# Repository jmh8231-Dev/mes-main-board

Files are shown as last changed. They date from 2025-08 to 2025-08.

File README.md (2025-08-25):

# MES Main Board (Rev 1.0)

STM32MP257 기반 임베디드 메인보드. DSI→HDMI, GbE, Wi-Fi/BT, eMMC/µSD/QSPI, USB 허브, CAN-FD, 하이파이 오디오 체인을 단일 보드에 통합하였다. 전원은 ATX-24로부터 공급되며, 보조 MCU ATmega328P가 “SoftKill Power” 시퀀스를 통해 안전한 전원 관리와 강제 종료 로깅을 담당한다.

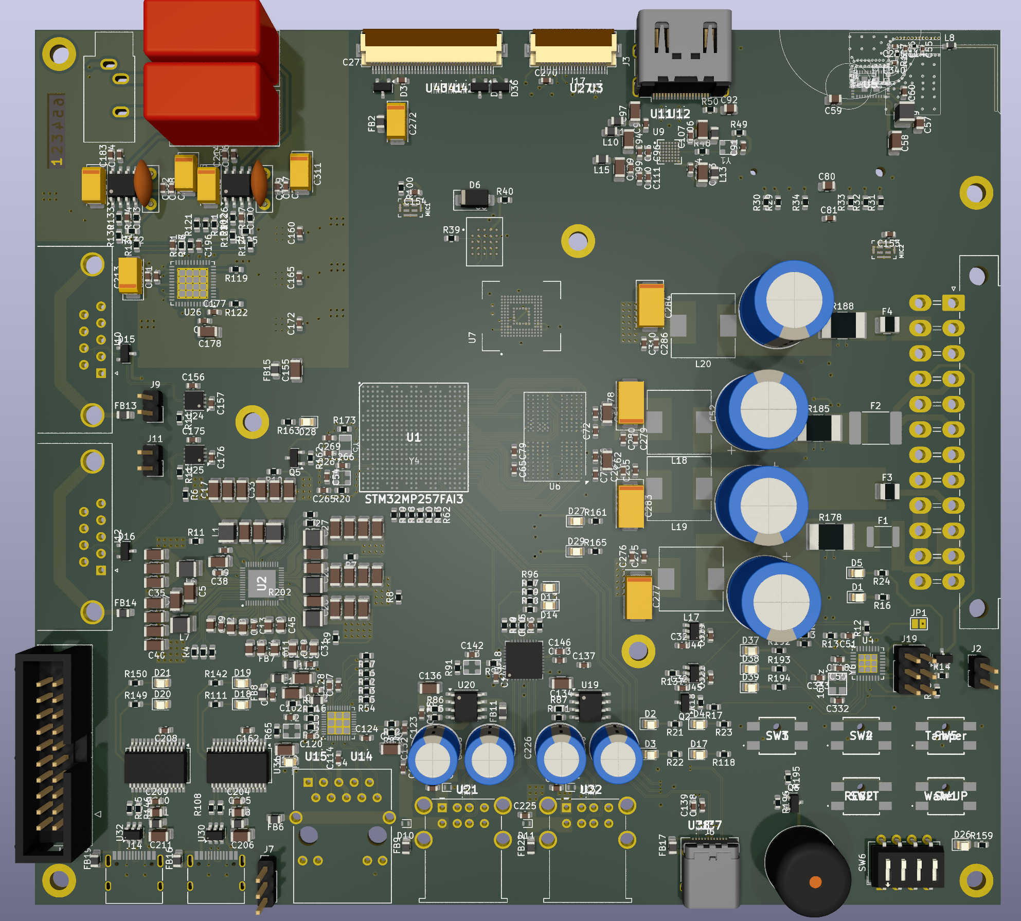
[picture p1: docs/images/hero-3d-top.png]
3D Render Top


---

## 1. 핵심 사양

- **MPU**: ST **STM32MP257FAI3** (Cortex-A35 듀얼 + Cortex-M33)
- **메모리/부트**
  - LPDDR4: **Micron MT53E1G32D2FW-046**
  - eMMC: **KIOXIA THGAMVG8T13BAIL**
  - QSPI-NOR: **Macronix MX25L51245G**
  - microSD: **GSD090012SEU**
- **네트워킹**
  - Gigabit PHY: **Realtek RTL8211F-CG**
  - MagJack: **48F-01GYD2NL**
- **무선**: **Murata LBEE5KL1YN-814** (802.11b/g/n, BT v5.2, SDIO + UART/PCM)
- **비디오/디스플레이**
  - **Analog Devices ADV7535** (MIPI-DSI → HDMI 1.4)
  - HDMI ESD 보호: **HDMI05-CL02F3**
  - LVDS 패널 커넥터 제공
- **USB**
  - **Microchip USB2514B** 4-포트 USB 2.0 허브
  - USB-C(2계통: A35 경로 / M33 경로), USB 3.0 Type-A, Stacked USB-A
- **필드버스**: **MCP2562FD** CAN-FD 트랜시버 ×2, ESDCAN 보호소자
- **오디오 체인**
  - DAC: **AK4458VN**(8채널)
  - Op-Amp: **OPA1611**
  - 저노이즈 LDO: **TPS7A4701 / TPS7A3301**(±전원)
- **전원/시퀀싱**
  - PMIC: **STPMIC25**
  - 입력: **ATX-24**
- **클록**: 24/25/40 MHz TCXO, 32.768 kHz RTC, 16 MHz(ATmega)

부품 요약 CSV: `docs/mes_key_components.csv`

---

## 2. 시스템 구성 개요

- **스토리지 계층**: QSPI-NOR(부트로더) → eMMC(루트 파일시스템) + microSD(리커버리/업데이트)
- **그래픽 파이프라인**: MPU MIPI-DSI → ADV7535 변환 → HDMI(DDC/EDID/HPD/CEC)
- **네트워크**: RGMII 기반 1 GbE(Phy RTL8211F-CG + MagJack)
- **무선**: SDIO 4-bit + LPO/WAKE, 40 MHz TCXO, 안테나 π-네트워크
- **오디오**: AK4458 → OPA1611(Line-out), ±레일 저노이즈 LDO로 SNR/THD 최적화
- **필드버스**: MCP2562FD ×2, 종단 저항/보호소자 구성

이미지 참조:
- 레이아웃: `docs/images/pcb-layout.png`
- 탑레벨 스키매틱: `docs/images/schematic-overview.png`
- Ethernet/Video/Storage/Wi-Fi/Audio/PMIC/DDR 등: `docs/images/` 하위 파일

---

## 3. SoftKill Power (ATmega328P)

전원은 **ATX-24**에서 입력되며, 보조 MCU **ATmega328P**가 PSU의 **PS_ON#**과 **PWR_OK**를 제어·감시한다.

### 3.1 정상 동작 시퀀스
1. **Power On**: 사용자가 Power SW를 누르면 ATmega가 PS_ON#을 구동하여 PSU를 켬 → **PWR_OK** 감시 → **MPU_WakeUP** 신호 출력.
2. **Power Down**: Power SW 또는 GUI의 “전원 끄기” → ATmega가 **종료 요청**을 MPU에 전달 → MPU가 모듈별 종료를 수행하고 ‘Shut-OK’ 회신 → ATmega가 전원 차단.

### 3.2 강제 종료 시퀀스
- **조건**: Power SW를 **n초 이상** 지속 입력.
- **처리**
  - ATmega가 **강제종료 이벤트**를 **EEPROM**에 기록하고 MPU에 이벤트 통보.
  - **MPU 응답**: 최대 n초 동안 모듈 종료 대기 → MPU의 ‘Shut-OK’ 수신 시 전원 차단(시간 초과 시에도 차단).
  - **MPU 무응답**: 즉시 전원 차단.

### 3.3 ATmega 리셋 방법
1) AC 코드 분리  2) **JP1 쇼트**로 하드 리셋.

---

## 4. Bring-up 절차

1. **전원/시퀀스**: STPMIC25 레일 타이밍·리플 측정, ATX 입력 보호/서지 경로 확인.
2. **LPDDR4**: TF-A/U-Boot에서 training 로그 확인, `memtester`로 장시간 스트레스.
3. **부트체인**: QSPI-NOR → eMMC 부팅 확인, microSD 리커버리 경로 검증.
4. **Ethernet**: RGMII 타이밍/strap, MDIO 주소 확인, `iperf3` 스루풋 측정.
5. **Display**: ADV7535 I²C 접근, EDID/HPD/CEC 정상 → 720p → 1080p 순으로 검증.
6. **Wi-Fi/BT**: SDIO 25/50 MHz 단계 bring-up, NVRAM/FW 로딩, 안테나 VSWR 체크.
7. **USB 허브**: USB2514B enumerate, 각 포트 전류 한계/ESD 보호 확인.
8. **CAN-FD**: 루프백/피어 통신(500 kbps/2 Mbps), 종단 저항 설정 검증.
9. **Audio**: I²S/TDM 클록(256fs/512fs) 정합, 라인아웃 SNR/THD 측정.

---

## 5. Linux 디바이스트리 체크리스트

- SoC: `st,stm32mp25` / PMIC: `st,stpmic25`(레일/시퀀스/IRQ)
- QSPI NOR: `mx25l51245g` (bootloader/MTD 파티션)
- MMC: `mmc0`=eMMC(HS200/HS400), `mmc1`=µSD(UHS-I)
- MIPI-DSI + `adv7535`(HPD/CEC/DDC)
- Ethernet: RGMII + `realtek,rtl8211f` PHY 노드
- Wi-Fi/BT: SDIO(LBEE5KL1YN-814), BT UART/PCM, 32 kHz LPO
- USB: root hub + `microchip,usb2514b`(리셋 GPIO 있으면 명시), Type-C CC/role
- CAN-FD: `mcp2562fd` enable/standby GPIO
- Audio: `ak4458` codec, I²S/TDM DAI-link
- ATmega328P: 보조 MCU 인터페이스(UART/I²C/SPI) 노드

---

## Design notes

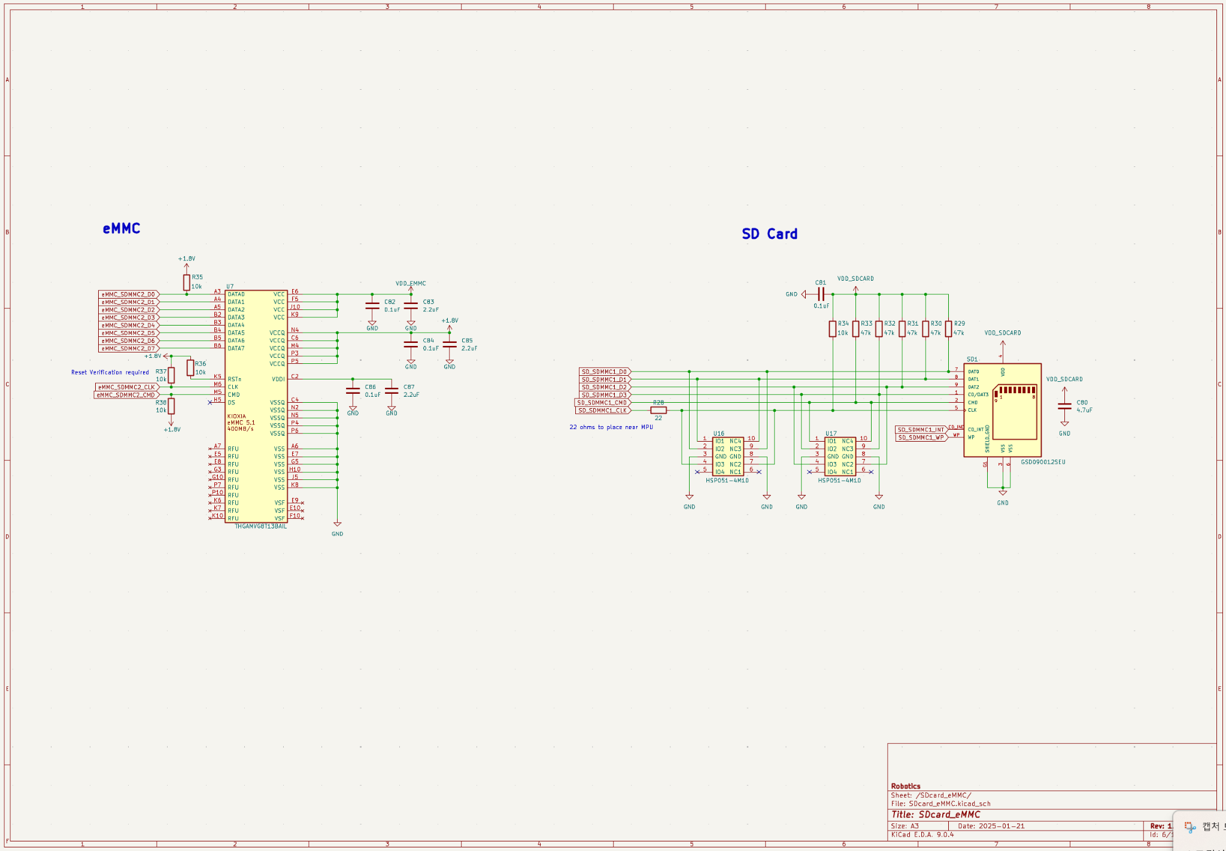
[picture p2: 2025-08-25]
docs/images/schematic-sd-emmc.png

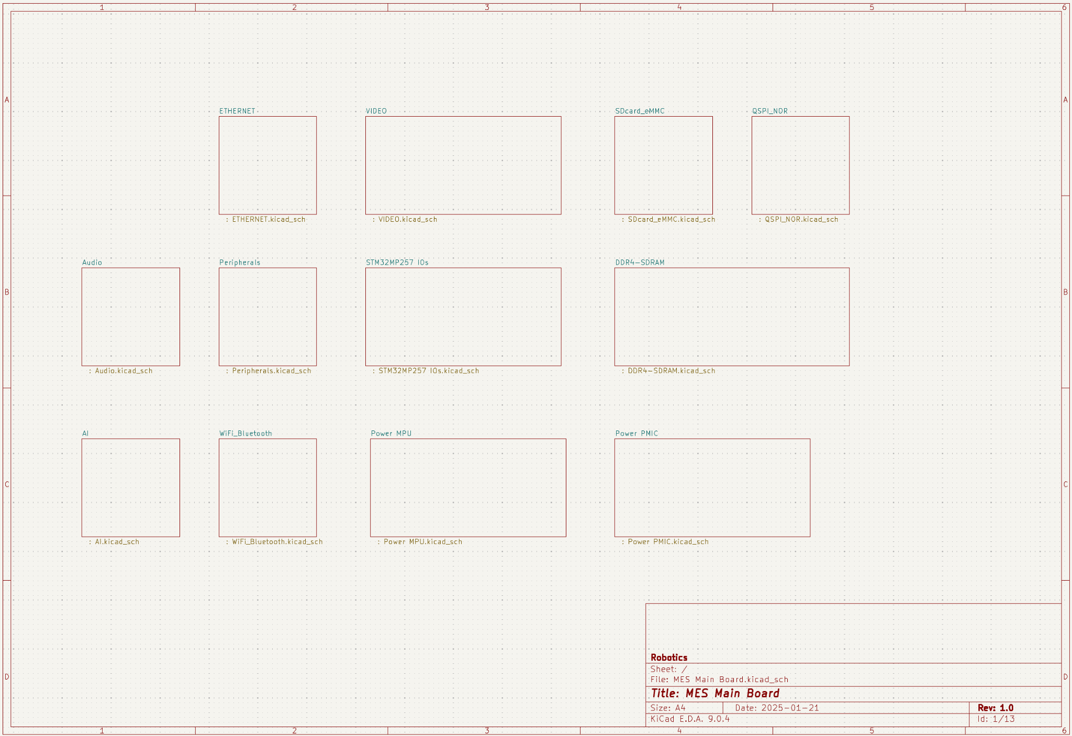
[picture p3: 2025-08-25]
docs/images/schematic-overview.png

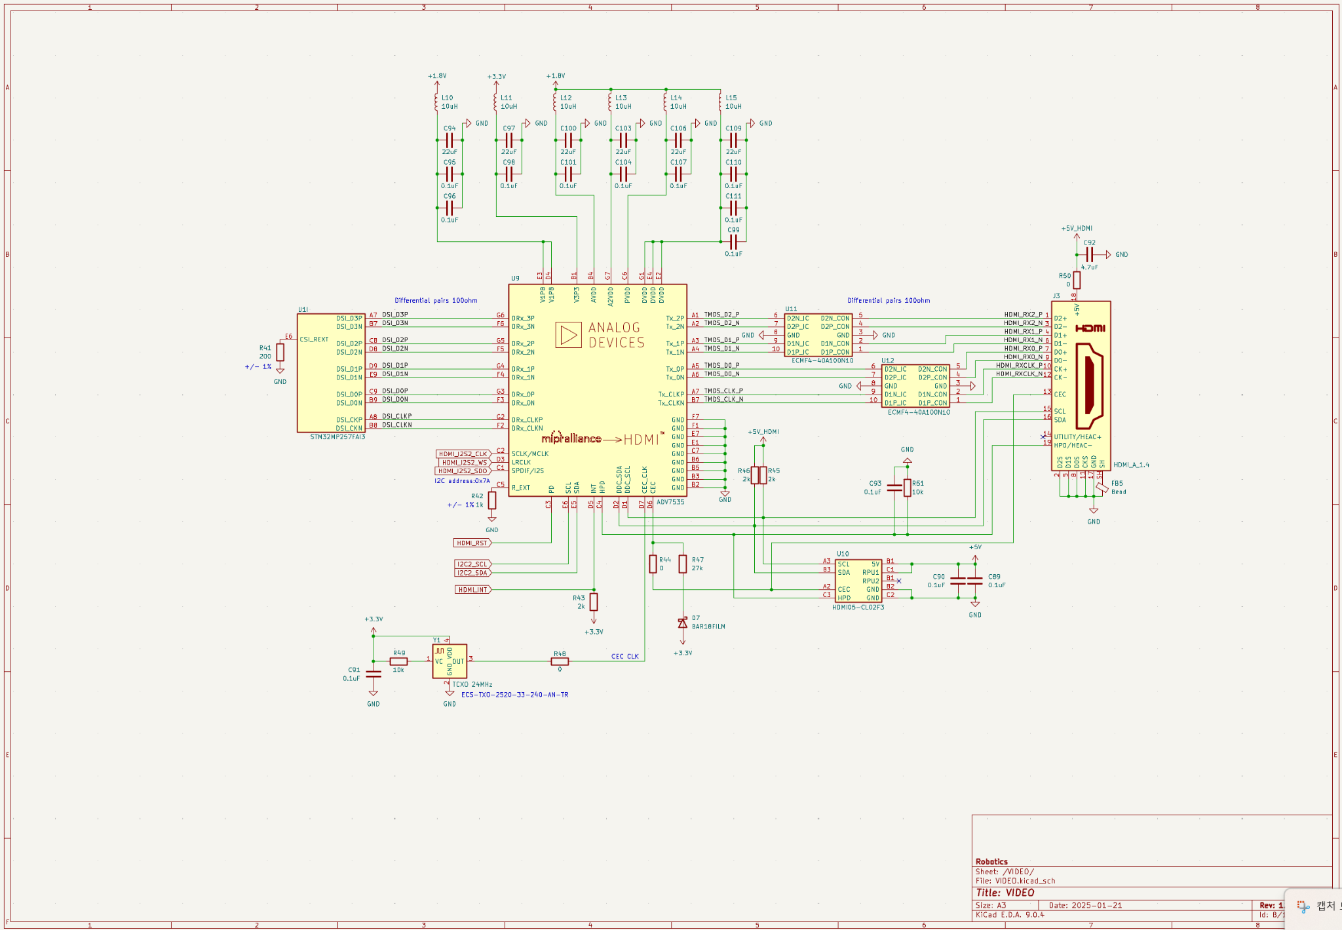
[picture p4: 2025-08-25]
docs/images/schematic-video.png

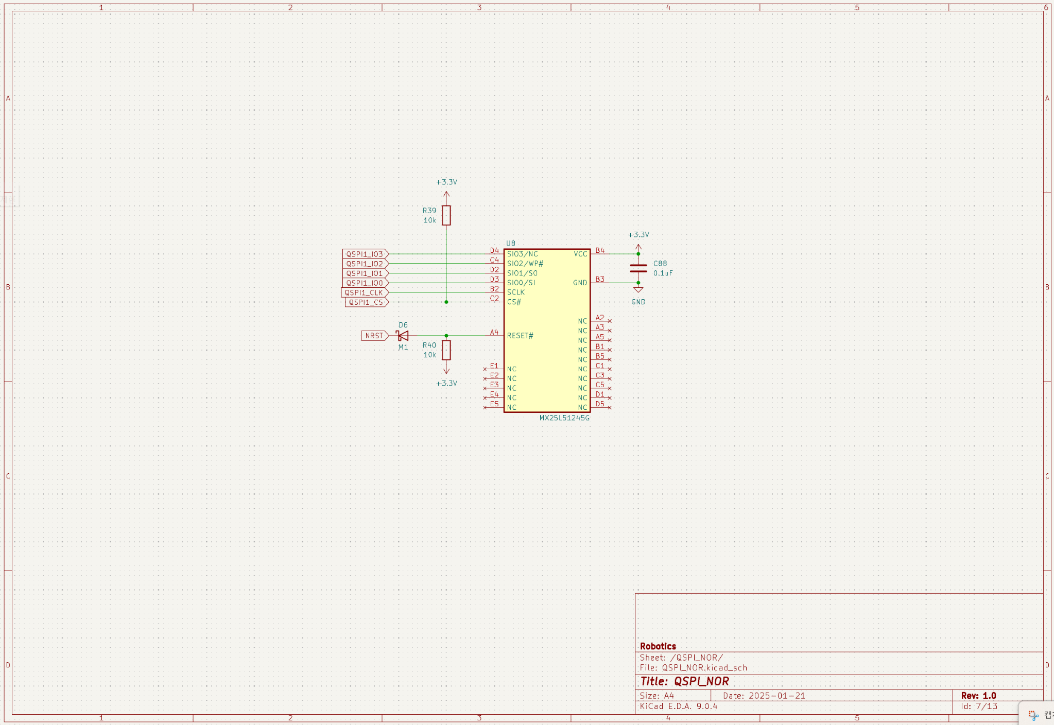
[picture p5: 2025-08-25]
docs/images/schematic-qspi.png

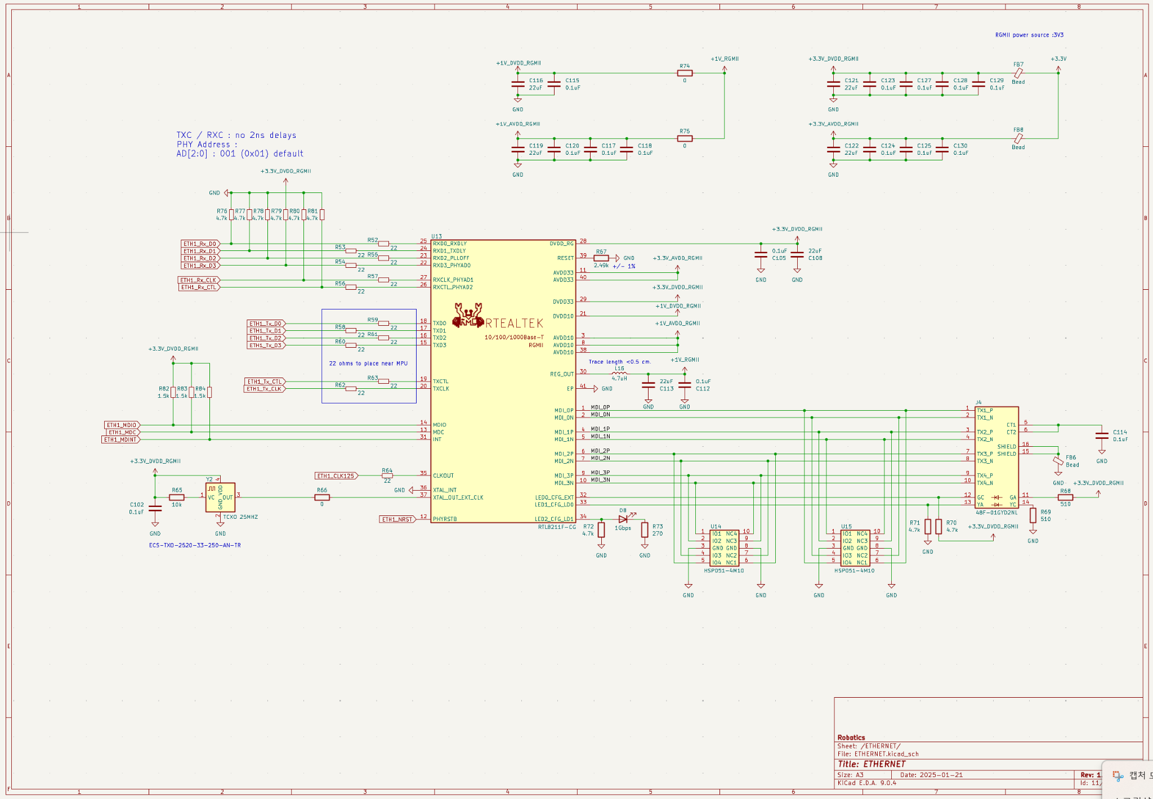
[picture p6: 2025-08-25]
docs/images/schematic-ethernet.png

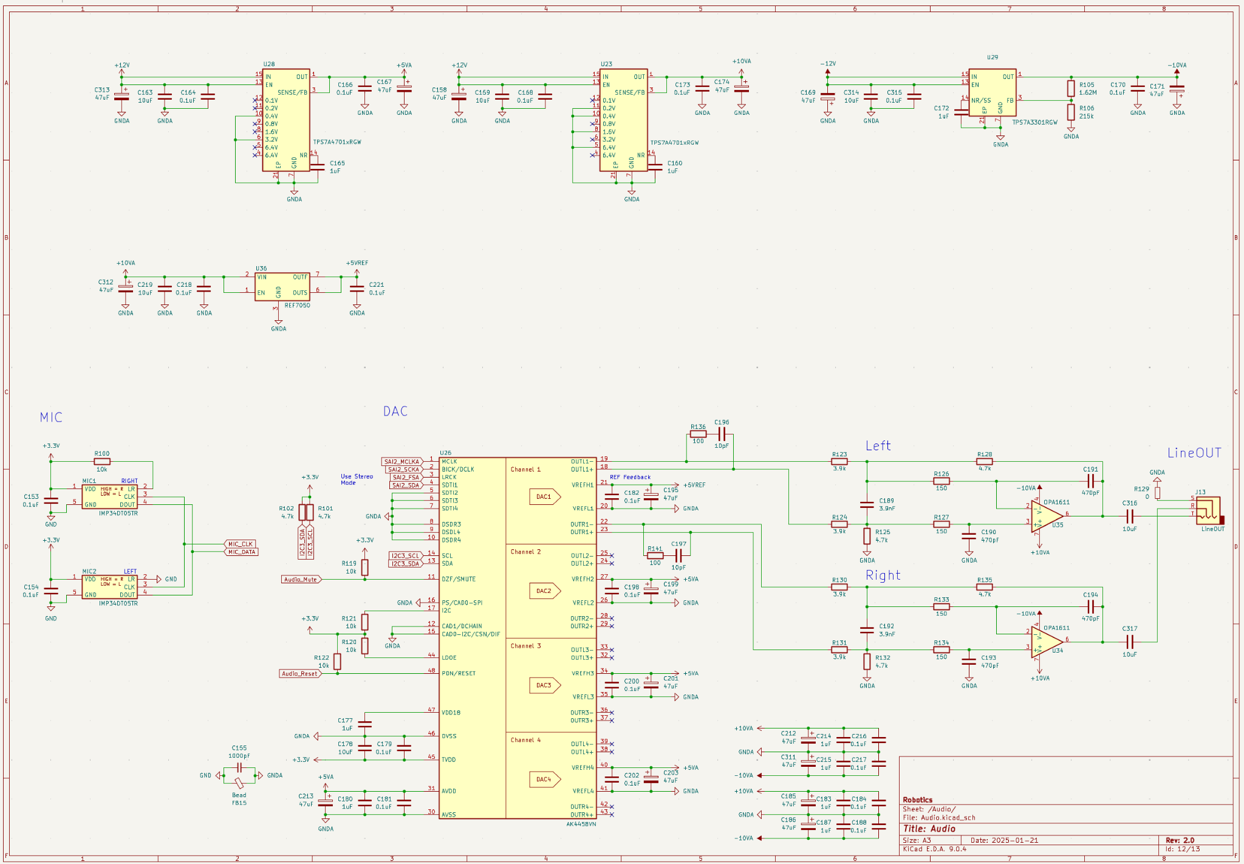
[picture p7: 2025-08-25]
docs/images/schematic-audio.png

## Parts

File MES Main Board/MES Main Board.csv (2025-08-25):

Reference | Value | Datasheet | Footprint | Qty | DNP
AE1 | P2ML4452-1-A.DXF | ~ | PCB:LBEE5KL1YN_ANT | 1
BT1 | CR2032 | ~ | PCB:BAT-HLD-001 | 1
BZ1 | Buzzer | ~ | Buzzer_Beeper:Buzzer_12x9.5RM7.6 | 1
C1,C2,C3,C4,C5,C6,C7,C39,C58,C61,C62,C68,C69,C159,C163,C178,C206,C211,C219,C220,C314,C316,C317 | 10uF | ~ | -- 섞인 값 -- | 23
C8,C9,C12,C13,C38,C51,C148,C160,C165,C172,C177,C180,C183,C187,C214,C215,C228,C229,C230,C231,C232,C234,C235,C236,C237,C241,C243,C244,C245,C246,C247,C249,C250,C251,C252,C256,C257,C258,C259,C262,C263,C264,C268,C270,C275,C279,C285,C286,C288,C289,C290,C291,C292,C293,C294,C295,C296,C297,C302 | 1uF | ~ | Capacitor_SMD:C_0603_1608Metric | 59
C10,C11,C29,C31,C44,C45,C46,C47,C48,C49,C57,C80,C92,C147,C205,C210,C299,C300 | 4.7uF | ~ | Capacitor_SMD:C_0805_2012Metric | 18
C14,C30,C50,C53,C54,C60,C63,C64,C65,C66,C67,C70,C71,C72,C73,C74,C75,C76,C77,C78,C79,C81,C82,C84,C86,C88,C89,C90,C91,C93,C95,C96,C98,C99,C101,C102,C104,C105,C107,C110,C111,C112,C114,C115,C117,C118,C120,C123,C124,C125,C127,C128,C129,C130,C131,C133,C135,C137,C138,C139,C141,C142,C143,C144,C145,C146,C149,C150,C151,C152,C153,C154,C156,C157,C161,C162,C164,C166,C168,C170,C173,C175,C176,C179,C181,C182,C184,C188,C198,C200,C202,C204,C207,C208,C209,C216,C217,C218,C221,C222,C223,C224,C225,C233,C238,C239,C240,C242,C248,C253,C254,C255,C260,C261,C271,C273,C276,C280,C287,C298,C301,C303,C304,C305,C306,C307,C308,C309,C310,C315,C318,C319,C320,C321,C322,C323,C324,C325,C326,C327,C328,C329,C330,C331 | 0.1uF | ~ | Capacitor_SMD:C_0603_1608Metric | 144
C15,C16,C17,C18,C19,C20,C21,C22,C23,C24,C25,C26,C27,C28,C32,C33,C34,C35,C36,C37,C40,C41,C42,C43,C94,C97,C100,C103,C106,C108,C109,C113,C116,C119,C121,C122 | 22uF | ~ | Capacitor_SMD:C_1206_3216Metric | 36
C52,C274,C281,C282 | 2200uF | ~ | Capacitor_THT:CP_Radial_D12.5mm_P5.00mm | 4
C55,C56 | C | ~ | Capacitor_SMD:C_0805_2012Metric | 2
C59,C83,C85,C87,C227 | 2.2uF | ~ | Capacitor_SMD:C_0805_2012Metric | 5
C126,C132,C134,C136,C140,C226 | 220uF | ~ | Capacitor_THT:CP_Radial_D8.0mm_P3.50mm | 6
C155 | 1000pF | ~ | Capacitor_SMD:C_1206_3216Metric | 1
C158,C167,C169,C171,C174,C185,C186,C195,C199,C201,C203,C212,C213,C272,C311,C312,C313 | 47uF | ~ | -- 섞인 값 -- | 17
C189,C192 | 3.9nF | ~ | Capacitor_THT:C_Disc_D7.5mm_W2.5mm_P5.00mm | 2
C190,C191,C193,C194 | 470pF | ~ | Capacitor_SMD:C_0603_1608Metric | 4
C196,C197 | 10pF | ~ | Capacitor_SMD:C_0603_1608Metric | 2
C265,C266,C267,C269 | 6.8pF | ~ | Capacitor_SMD:C_0603_1608Metric | 4
C277,C278,C283,C284 | 100uF | ~ | Capacitor_Tantalum_SMD:CP_EIA-7343-30_AVX-N | 4
C332,C333 | 22pF | ~ | Capacitor_SMD:C_0603_1608Metric | 2
D1 | PWR OK | ~ | LED_SMD:LED_0805_2012Metric | 1
D2 | +12V | ~ | LED_SMD:LED_0805_2012Metric | 1
D3 | +5V | ~ | LED_SMD:LED_0805_2012Metric | 1
D4 | +5VSB | ~ | LED_SMD:LED_0805_2012Metric | 1
D5 | PS ON | ~ | LED_SMD:LED_0805_2012Metric | 1
D6 | SS54 | ~ | Diode_SMD:D_SMC | 1
D7 | BAR18FILM | www.st.com/resource/en/datasheet/bar42.pdf | Package_TO_SOT_SMD:SOT-23 | 1
D8 | 1Gbps | ~ | LED_SMD:LED_0805_2012Metric | 1
D9,D10,D11,D12 | ESDA7P120-1U1M | ~ | Diode_SMD:ST_QFN-2L_1.6x1.0mm | 4
D13 | SUSP IND | ~ | LED_SMD:LED_0805_2012Metric | 1
D14 | HS INT | ~ | LED_SMD:LED_0805_2012Metric | 1
D15,D16 | ESDCAN24-2BLY | https://www.littelfuse.com/~/media/electronics/datasheets/tvs_diode_arrays/littelfuse_tvs_diode_array_sm712_datasheet.pdf.pdf | Package_TO_SOT_SMD:SOT-23 | 2
D17 | -12V | ~ | LED_SMD:LED_0805_2012Metric | 1
D18 | A35 Rx | ~ | LED_SMD:LED_0805_2012Metric | 1
D19 | A35 Tx | ~ | LED_SMD:LED_0805_2012Metric | 1
D20 | M33 Rx | ~ | LED_SMD:LED_0805_2012Metric | 1
D21 | M33 Tx | ~ | LED_SMD:LED_0805_2012Metric | 1
D22,D23,D24,D25 | ESDALC6V1 | ~ | Diode_SMD:D_SOD-882D | 4
D26 | RED | ~ | LED_SMD:LED_0805_2012Metric | 1
D27 | G | ~ | LED_SMD:LED_0805_2012Metric | 1
D28 | B | ~ | LED_SMD:LED_0805_2012Metric | 1
D29 | O | ~ | LED_SMD:LED_0805_2012Metric | 1
D30,D31,D32,D33,D34,D35,D36 | ESDA5V3L | http://www.onsemi.com/pub/Collateral/MMBZ5V6ALT1-D.PDF | Package_TO_SOT_SMD:SOT-23 | 7
D37 | PMIC | ~ | LED_SMD:LED_0805_2012Metric | 1
D38 | OCP | ~ | LED_SMD:LED_0805_2012Metric | 1
D39 | OVP | ~ | LED_SMD:LED_0805_2012Metric | 1
F1 | 2.5A | ~ | Fuse:Fuse_1812_4532Metric | 1
F2 | 3A | ~ | Fuse:Fuse_2920_7451Metric | 1
F3,F4 | 500mA | ~ | Fuse:Fuse_1210_3225Metric | 2
FB1,FB2,FB3,FB4,FB5,FB6,FB7,FB8,FB9,FB10,FB11,FB12,FB13,FB14,FB15,FB16,FB17,FB18,FB19,FB20,FB21,FB22 | Bead | ~ | Inductor_SMD:L_0805_2012Metric | 22
J1 | ATX-24 | https://www.intel.com/content/dam/www/public/us/en/documents/guides/power-supply-design-guide-june.pdf | Connector_Molex:Molex_Mini-Fit_Jr_5569-24A1_2x12_P4.20mm_Horizontal | 1
J2 | Power SW | ~ | Connector_PinHeader_2.54mm:PinHeader_1x02_P2.54mm_Vertical | 1
J3 | HDMI_A_1.4 | https://en.wikipedia.org/wiki/HDMI | Connector_Video:HDMI_A_Molex_208658-1001_Horizontal | 1
J4 | 48F-01GYD2NL |  | Connector_RJ:RJ45_Wuerth_7499111446_Horizontal | 1
J5,J16 | USB_A_Stacked | ~ | Connector_USB:USB_A_Wuerth_61400826021_Horizontal_Stacked | 2
J6 | USB 3.0 | https://www.usb.org/sites/default/files/documents/usb_type-c.zip | Connector_USB:USB_C_Receptacle_Amphenol_12401610E4-2A | 1
J7 | RFID | ~ | Connector_PinHeader_2.54mm:PinHeader_1x03_P2.54mm_Vertical | 1
J8 | USB Type C(A35) | https://www.usb.org/sites/default/files/documents/usb_type-c.zip | Connector_USB:USB_C_Receptacle_HRO_TYPE-C-31-M-12 | 1
J9 | CAN1 T-Res | ~ | Connector_PinHeader_2.54mm:PinHeader_1x02_P2.54mm_Vertical | 1
J10 | FDCAN_1 | ~ | Connector_Dsub:DSUB-9_Female_Horizontal_P2.77x2.84mm_EdgePinOffset7.70mm_Housed_MountingHolesOffset9.12mm | 1
J11 | CAN2 T-Res | ~ | Connector_PinHeader_2.54mm:PinHeader_1x02_P2.54mm_Vertical | 1
J12 | FDCAN_2 | ~ | Connector_Dsub:DSUB-9_Female_Horizontal_P2.77x2.84mm_EdgePinOffset7.70mm_Housed_MountingHolesOffset9.12mm | 1
J13 | LineOUT | ~ | Connector_Audio:Jack_3.5mm_CUI_SJ1-3533NG_Horizontal | 1
J14 | USB Type C(M33) | https://www.usb.org/sites/default/files/documents/usb_type-c.zip | Connector_USB:USB_C_Receptacle_HRO_TYPE-C-31-M-12 | 1
J15 | ST-Link | ~ | Connector_IDC:IDC-Header_2x10_P2.54mm_Vertical | 1
J17 | 2-1734592-2 | ~ | Connector_FFC-FPC:Hirose_FH12-22S-0.5SH_1x22-1MP_P0.50mm_Horizontal | 1
J18 | LVDS | ~ | Connector_FFC-FPC:Hirose_FH12-40S-0.5SH_1x40-1MP_P0.50mm_Horizontal | 1
J19 | PMIC ISP | ~ | Connector_PinHeader_2.54mm:PinHeader_2x03_P2.54mm_Vertical | 1
JP1 | ATmega328p Reset | ~ | Jumper:SolderJumper-2_P1.3mm_Open_Pad1.0x1.5mm | 1
L1,L2,L3,L6,L7 | 0.68uH | ~ | Inductor_SMD:L_1210_3225Metric | 5
L4,L5,L9 | 2.2uH | ~ | Inductor_SMD:L_1210_3225Metric | 3
L8 | 2.4nH | ~ | Inductor_SMD:L_0603_1608Metric | 1
L10,L11,L12,L13,L14,L15 | 10uH | ~ | Inductor_SMD:L_0805_2012Metric | 6
L16 | 4.7uH | ~ | Inductor_SMD:L_0805_2012Metric | 1
L17,L18,L19,L20 | 47uH | ~ | Inductor_SMD:L_10.4x10.4_H4.8 | 4
MIC1,MIC2 | IMP34DT05TR | https://www.mouser.kr/datasheet/2/389/imp34dt05-1849335.pdf | PCB:MIC_MP34DT06JTR | 2
Q1,Q2,Q3,Q4,Q5,Q6 | BSS138 | https://www.onsemi.com/pub/Collateral/BSS138-D.PDF | Package_TO_SOT_SMD:SOT-23 | 6
R1,R2,R3,R4,R5,R6,R7,R8,R9,R10,R11,R20,R44,R48,R50,R66,R74,R75,R92,R129,R138,R167,R172,R173,R175,R177,R179,R180,R181,R184,R186,R187,R189 | 0 | ~ | Resistor_SMD:R_0603_1608Metric | 33
R12,R13,R14,R18,R19,R21,R25,R34,R35,R36,R37,R38,R39,R40,R49,R51,R65,R85,R86,R87,R89,R90,R91,R100,R110,R112,R115,R118,R119,R120,R121,R122,R137,R139,R140,R148,R153,R160,R162,R164,R171,R176,R190,R191,R192,R193,R194,R196 | 10k | ~ | Resistor_SMD:R_0603_1608Metric | 48
R15,R17,R136,R141,R155,R195 | 100 | ~ | Resistor_SMD:R_0603_1608Metric | 6
R16,R22,R23,R24 | 3k | ~ | Resistor_SMD:R_0603_1608Metric | 4
R26,R27 | 240 | ~ | Resistor_SMD:R_0603_1608Metric | 2
R28,R52,R53,R54,R55,R56,R57,R58,R59,R60,R61,R62,R63,R64,R107,R108,R145,R146 | 22 | ~ | Resistor_SMD:R_0603_1608Metric | 18
R29,R30,R31,R32,R33 | 47k | ~ | Resistor_SMD:R_0603_1608Metric | 5
R41,R168,R169,R170,R174 | 200 | ~ | Resistor_SMD:R_0603_1608Metric | 5
R42,R97,R98,R111,R142,R149,R150,R152,R156,R157,R158 | 1k | ~ | Resistor_SMD:R_0603_1608Metric | 11
R43,R45,R46 | 2k | ~ | Resistor_SMD:R_0603_1608Metric | 3
R47 | 27k | ~ | Resistor_SMD:R_0603_1608Metric | 1
R67 | 2.49k | ~ | Resistor_SMD:R_0603_1608Metric | 1
R68,R69 | 510 | ~ | Resistor_SMD:R_0603_1608Metric | 2
R70,R71,R72,R76,R77,R78,R79,R80,R81,R101,R102,R109,R125,R128,R132,R135,R147,R182,R183 | 4.7k | ~ | Resistor_SMD:R_0603_1608Metric | 19
R73,R161,R163,R165 | 270 | ~ | Resistor_SMD:R_0603_1608Metric | 4
R82,R83,R84 | 1.5k | ~ | Resistor_SMD:R_0603_1608Metric | 3
R88,R94,R95,R96,R99,R166 | 100k | ~ | Resistor_SMD:R_0603_1608Metric | 6
R93 | 12k | ~ | Resistor_SMD:R_0603_1608Metric | 1
R103,R104,R143,R144 | 5.1k | ~ | Resistor_SMD:R_0603_1608Metric | 4
R105 | 1.62M | ~ | Resistor_SMD:R_0603_1608Metric | 1
R106 | 215k | ~ | Resistor_SMD:R_0603_1608Metric | 1
R113,R114,R116,R117 | 120 | ~ | Resistor_SMD:R_0603_1608Metric | 4
R123,R124,R130,R131 | 3.9k | ~ | Resistor_SMD:R_0603_1608Metric | 4
R126,R127,R133,R134 | 150 | ~ | Resistor_SMD:R_0603_1608Metric | 4
R151,R154,R159 | 330 | ~ | Resistor_SMD:R_0603_1608Metric | 3
R178,R185,R188 | 0.1 | ~ | Resistor_SMD:R_2816_7142Metric | 3
SD1 | GSD090012SEU |  | PCB:AMPHENOL_GSD090012SEU | 1
SW1 | WakeUP | ~ | PCB:TLSMDT3C020GLFS | 1
SW2 | RESET | ~ | PCB:TLSMDT3C020GLFS | 1
SW3 | SW1 | ~ | PCB:TLSMDT3C020GLFS | 1
SW4 | SW2 | ~ | PCB:TLSMDT3C020GLFS | 1
SW5 | Tamper | ~ | PCB:TLSMDT3C020GLFS | 1
SW6 | BOOT Mode | ~ | Button_Switch_THT:SW_DIP_SPSTx04_Slide_6.7x11.72mm_W7.62mm_P2.54mm_LowProfile | 1
U1 | STM32MP257FAI3 |  | PCB:BGA436C80P22X22_1800X1800X120 | 1
U2 | STPMIC25 |  | PCB:QFN40P650X650X90-57N-D | 1
U3,U11,U12,U21,U22,U41,U43 | ECMF4-40A100N10 | https://www.mouser.kr/datasheet/2/389/ecmf2_40a100n6-2935932.pdf | ECMF4-40A100N10:ECMF440A100N10 | 7
U4 | ATmega328P-M | http://ww1.microchip.com/downloads/en/DeviceDoc/ATmega328_P%20AVR%20MCU%20with%20picoPower%20Technology%20Data%20Sheet%2040001984A.pdf | Package_DFN_QFN:QFN-32-1EP_5x5mm_P0.5mm_EP3.1x3.1mm | 1
U5 | LBEE5KL1YN-814 | https://www.murata.com/products/productdata/8815814344734/type1yn.pdf | LBEE5KL1YN-814:LBEE5KL1YN814 | 1
U6 | MT53E1G32D2FW-046 | https://www.micron.com/content/dam/micron/global/secure/products/data-sheet/dram/mobile-dram/low-power-dram/lpddr4/auto-embedded/z42m/200b-z42m-automotive-lpd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 | Package_BGA:BGA-200_10.0x14.5mm_Layout12x22_P0.80x0.65mm | 1
U7 | THGAMVG8T13BAIL | https://www.mouser.kr/datasheet/2/1034/KIOXIA_e_MMC_Product_Brief-3193570.pdf | PCB:BGA153N50P14X14_1300X1150X100N | 1
U8 | MX25L51245G | https://www.mouser.kr/datasheet/2/819/MX25L51245G_2c_3V_2c_512Mb_2c_v1_7-3371024.pdf | PCB:BGA24C100P5X5_600X800X120 | 1
U9 | ADV7535 | https://www.analog.com/media/en/technical-documentation/data-sheets/ADV7535.pdf | PCB:BGA49N50P7X7_346X346X66 | 1
U10 | HDMI05-CL02F3 | https://www.mouser.kr/datasheet/2/389/hdmi05_cl02f3-1849217.pdf | HDMI05-CL02F3:BGA9C40P3X3_114X114X66 | 1
U13 | RTL8211F-CG |  | Package_DFN_QFN:QFN-40-1EP_5x5mm_P0.4mm_EP3.8x3.8mm | 1
U14,U15,U16,U17 | HSP051-4M10 | https://www.st.com/content/ccc/resource/technical/document/datasheet/44/a6/63/a5/b3/ae/4e/01/DM00089476.pdf/files/DM00089476.pdf/jcr:content/translations/en.D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 | HSP051-4M10:HSP0514M10 | 4
U18 | USB2514B_Bi | http://ww1.microchip.com/downloads/en/DeviceDoc/00001692C.pdf | Package_DFN_QFN:QFN-36-1EP_6x6mm_P0.5mm_EP3.7x3.7mm | 1
U19,U20 | STMPS2252MTR | https://www.st.com/content/ccc/resource/technical/document/datasheet/3d/38/34/c5/d0/fb/42/ce/CD00210593.pdf/files/CD00210593.pdf/jcr:content/translations/en.C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 | Package_SO:SOIC-8_3.9x4.9mm_P1.27mm | 2
U23,U28 | TPS7A4701xRGW | https://www.ti.com/lit/ds/symlink/tps7a47.pdf | Package_DFN_QFN:Texas_RGW0020A_VQFN-20-1EP_5x5mm_P0.65mm_EP3.15x3.15mm_ThermalVias | 2
U24,U25 | MCP2562FD | http://ww1.microchip.com/downloads/en/DeviceDoc/25167A.pdf | Package_DFN_QFN:DFN-8-1EP_3x3mm_P0.65mm_EP1.55x2.4mm | 2
U26 | AK4458VN | https://www.akm.com/content/dam/documents/products/audio/audio-dac/ak4458vn/ak4458vn-en-datasheet.pdf | Package_DFN_QFN:QFN-48-1EP_7x7mm_P0.5mm_EP5.1x5.1mm_ThermalVias | 1
U27,U37,U38,U39,U42 | ECMF2-40A100N6 |  | ECMF2-40A100N6:ECMF240A100N6 | 5
U29 | TPS7A3301RGW | https://www.ti.com/lit/ds/symlink/tps7a33.pdf | Package_DFN_QFN:Texas_RGW0020A_VQFN-20-1EP_5x5mm_P0.65mm_EP3.15x3.15mm_ThermalVias | 1
U30,U32 | TVS | https://www.we-online.com/components/products/datasheet/82400102.pdf | Package_TO_SOT_SMD:SOT-23-6 | 2
U31,U33 | FT232RL | https://www.ftdichip.com/Support/Documents/DataSheets/ICs/DS_FT232R.pdf | Package_SO:SSOP-28_5.3x10.2mm_P0.65mm | 2
U34,U35 | OPA1611 | http://www.ti.com/lit/ds/symlink/opa197.pdf | Package_SO:SOIC-8_3.9x4.9mm_P1.27mm | 2
U36 | REF7050 | https://www.ti.com/lit/ds/symlink/ref70.pdf?ts=1704274610714 | Package_SO:VSSOP-8_3x3mm_P0.65mm | 1
U40 | FUSB340TMX | https://www.onsemi.com/pdf/datasheet/fusb340-d.pdf | FUSB340TMX:FUSB340TMX | 1
U44,U45 | SN74LVC1T45DBV | http://www.ti.com/lit/ds/symlink/sn74lvc1t45.pdf | Package_TO_SOT_SMD:SOT-23-6 | 2
U46,U47,U48 | INA219BxD | http://www.ti.com/lit/ds/symlink/ina219.pdf | Package_SO:SOIC-8_3.9x4.9mm_P1.27mm | 3
Y1,Y3 | TCXO 24MHz | https://foxonline.com/wp-content/uploads/pdfs/T5HN_T5HV.pdf | PCB:ECS-TXO-2520 | 2
Y2 | TCXO 25MHZ | https://foxonline.com/wp-content/uploads/pdfs/T5HN_T5HV.pdf | PCB:ECS-TXO-2520 | 1
Y4 | TCXO 40MHZ | https://foxonline.com/wp-content/uploads/pdfs/T5HN_T5HV.pdf | PCB:ECS-TXO-2520 | 1
Y5 | 32.768kHz | ~ | PCB:ECX-.327-CDX-1293 | 1
Y6 | 16MHz | ~ | PCB:TSX-3225 16.0000MF18X-AC0 | 1

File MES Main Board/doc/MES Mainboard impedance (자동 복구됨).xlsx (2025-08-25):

Layer | 6 Layer
Stack-up Options | JLC06161H-3313
Differential Signal Spacing | 0.15mm
Impedance trace to copper | 0.5mm
Version with GND Copper Pour
Layer | Signal Name | single-ended 50 ohm | Calculated Trace Width(mm) | single-ended 55 ohm | Calculated Trace Width(mm) | Differential 90 ohm | Calculated Trace Width(mm) | Differential 100 ohm | Calculated Trace Width(mm) | Differential 120 ohm | Calculated Trace Width(mm)
L1 | SIG+GND | signal | 0.1565 | signal | 0.1267 | signal | 0.1412 | signal | 0.1082 | signal | Cannot be calculated
L2 | GND
L3 | SIG + GND | signal | 0.1425 | signal | 0.1153 | signal | 0.1285 | signal | 0.0988 | signal | Cannot be calculated
L4 | GND/PWR
L5 | GND/PWR
L6 | SIG + GND | signal | 0.1565 | signal | 0.1267 | signal | 0.1412 | signal | 0.1082 | signal | Cannot be calculated
Version without GND Copper Pour
Layer | Signal Name | single-ended 50 ohm | Calculated Trace Width(mm) | single-ended 55 ohm | Calculated Trace Width(mm) | Differential 90 ohm | Calculated Trace Width(mm) | Differential 100 ohm | Calculated Trace Width(mm) | Differential 120 ohm | Calculated Trace Width(mm)
L1 | SIG | signal | 0.1565 | signal | 0.1267 | signal | 0.141 | signal | 0.108 | signal | Cannot be calculated
L2 | GND
L3 | SIG | signal | 0.1425 | signal | 0.1153 | signal | 0.1285 | signal | 0.1 | signal | Cannot be calculated
L4 | GND/PWR
L5 | GND/PWR
L6 | SIG | signal | 0.1565 | signal | 0.1267 | signal | 0.141 | signal | 0.108 | signal | Cannot be calculated
